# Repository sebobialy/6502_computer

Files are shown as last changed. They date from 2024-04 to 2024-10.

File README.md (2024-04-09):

# 6502_computer
Simple 6502 DIY computer for peripheral prototyping
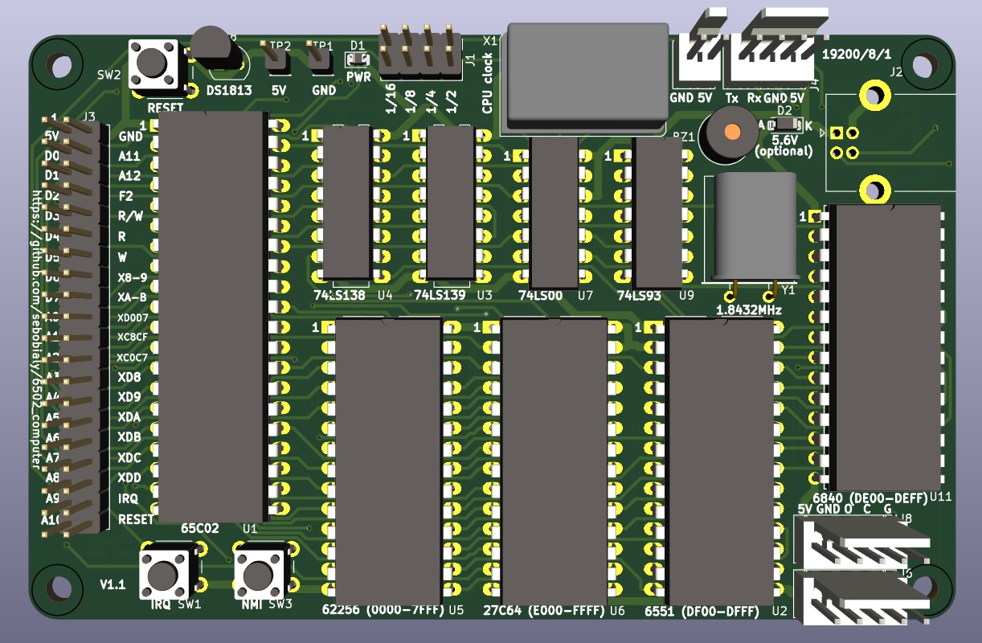
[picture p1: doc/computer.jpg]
6502_computer

**This is a work in progress. Do not try to manufacture yet.**
# Features
1. 65C02 with selectable speed
2. 6551 UART/ACIA with optional USB support via CH340N
3. 6840 clock chip (with buzzer attached)
4. CPU bus accessible, with several selection signals for various parts of memory
5. SyMon III directly working through UART/USB
6. Simple emulator
7. PCB with all possible markings, memory map, and values
8. Compact form, retro look&feel

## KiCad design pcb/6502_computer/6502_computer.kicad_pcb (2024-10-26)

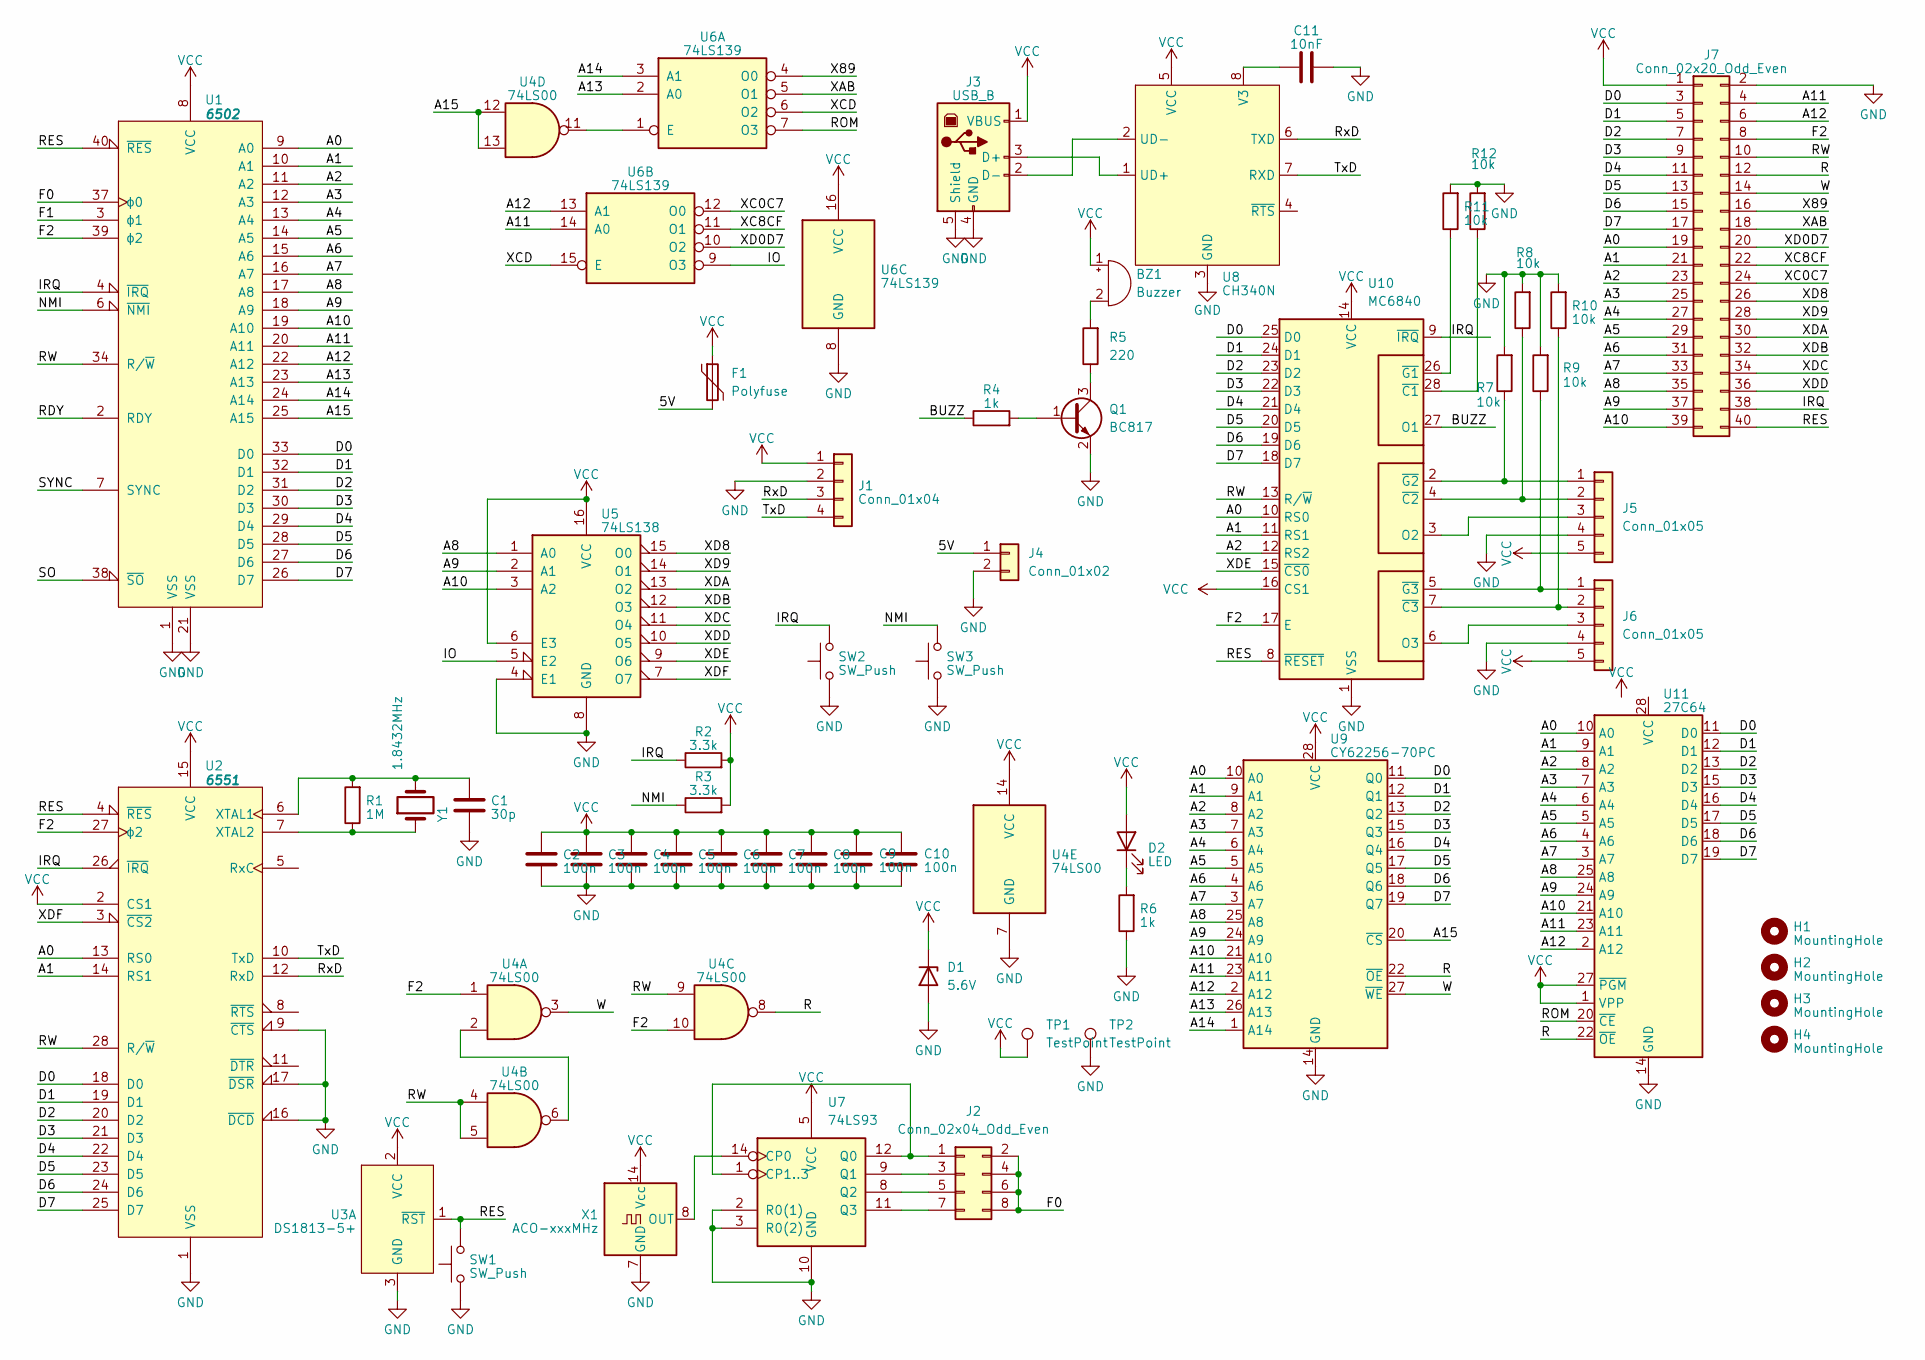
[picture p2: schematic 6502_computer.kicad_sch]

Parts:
BZ1: Buzzer; MagneticBuzzer_Kingstate_KCG0601
C1: 30p; C_0805_2012Metric
C2, C3, C4, C5, C6, C7, C8, C9, C10: 100n; C_0805_2012Metric
C11: 10nF; C_0805_2012Metric
D1: 5.6V; D_SOD-123
D2: LED; D_0805_2012Metric
F1: Polyfuse; Fuse_0805_2012Metric
H1, H2, H3, H4: MountingHole; MountingHole_3.2mm_M3
J1: Conn_01x04; Molex_KK-254_AE-6410-04A_1x04_P2.54mm_Vertical
J2: Conn_02x04_Odd_Even; PinHeader_2x04_P2.54mm_Vertical
J3: USB_B; USB_B_Lumberg_2411_02_Horizontal
J4: Conn_01x02; Molex_KK-254_AE-6410-02A_1x02_P2.54mm_Vertical
J5, J6: Conn_01x05; Molex_KK-254_AE-6410-05A_1x05_P2.54mm_Vertical
J7: Conn_02x20_Odd_Even; PinHeader_2x20_P2.54mm_Vertical
Q1: BC817; SOT-23
R1: 1M; R_0805_2012Metric
R2, R3: 3.3k; R_0805_2012Metric
R4, R6: 1k; R_0805_2012Metric
R5: 220; R_0805_2012Metric
R7, R8, R9, R10, R11, R12: 10k; R_0805_2012Metric
SW1, SW2, SW3: SW_Push; SW_PUSH_6mm_H4.3mm
TP1, TP2: TestPoint; PinHeader_1x01_P2.54mm_Vertical
U1: 6502; DIP-40_W15.24mm_LongPads
U2: 6551; DIP-28_W15.24mm_LongPads
U3: DS1813-5+; TO-92
U4: 74LS00; DIP-14_W7.62mm_LongPads
U5: 74LS138; DIP-16_W7.62mm_LongPads
U6: 74LS139; DIP-16_W7.62mm_LongPads
U7: 74LS93; DIP-14_W7.62mm_LongPads
U8: CH340N; SOP-8_3.9x4.9mm_P1.27mm
U9: CY62256-70PC; DIP-28_W15.24mm_LongPads
U10: MC6840; DIP-28_W15.24mm_LongPads
U11: 27C64; DIP-28_W15.24mm_LongPads
X1: ACO-xxxMHz; Oscillator_DIP-14
Y1: 1.8432MHz; Crystal_HC18-U_Horizontal

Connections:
/5V: F1.2, J4.1
/A0: J7.19, U1.9 (A0), U2.13 (RS0), U9.10 (A0), U10.10 (RS0), U11.10 (A0)
/A1: J7.21, U1.10 (A1), U2.14 (RS1), U9.9 (A1), U10.11 (RS1), U11.9 (A1)
/A2: J7.23, U1.11 (A2), U9.8 (A2), U10.12 (RS2), U11.8 (A2)
/A3: J7.25, U1.12 (A3), U9.7 (A3), U11.7 (A3)
/A4: J7.27, U1.13 (A4), U9.6 (A4), U11.6 (A4)
/A5: J7.29, U1.14 (A5), U9.5 (A5), U11.5 (A5)
/A6: J7.31, U1.15 (A6), U9.4 (A6), U11.4 (A6)
/A7: J7.33, U1.16 (A7), U9.3 (A7), U11.3 (A7)
/A8: J7.35, U1.17 (A8), U5.1 (A0), U9.25 (A8), U11.25 (A8)
/A9: J7.37, U1.18 (A9), U5.2 (A1), U9.24 (A9), U11.24 (A9)
/A10: J7.39, U1.19 (A10), U5.3 (A2), U9.21 (A10), U11.21 (A10)
/A11: J7.4, U1.20 (A11), U6.14 (A0), U9.23 (A11), U11.23 (A11)
/A12: J7.6, U1.22 (A12), U6.13 (A1), U9.2 (A12), U11.2 (A12)
/A13: U1.23 (A13), U6.2 (A0), U9.26 (A13)
/A14: U1.24 (A14), U6.3 (A1), U9.1 (A14)
/A15: U1.25 (A15), U4.12, U4.13, U9.20 (~CS)
/BUZZ: R4.1, U10.27 (O1)
/D0: J7.3, U1.33 (D0), U2.18 (D0), U9.11 (Q0), U10.25 (D0), U11.11 (D0)
/D1: J7.5, U1.32 (D1), U2.19 (D1), U9.12 (Q1), U10.24 (D1), U11.12 (D1)
/D2: J7.7, U1.31 (D2), U2.20 (D2), U9.13 (Q2), U10.23 (D2), U11.13 (D2)
/D3: J7.9, U1.30 (D3), U2.21 (D3), U9.15 (Q3), U10.22 (D3), U11.15 (D3)
/D4: J7.11, U1.29 (D4), U2.22 (D4), U9.16 (Q4), U10.21 (D4), U11.16 (D4)
/D5: J7.13, U1.28 (D5), U2.23 (D5), U9.17 (Q5), U10.20 (D5), U11.17 (D5)
/D6: J7.15, U1.27 (D6), U2.24 (D6), U9.18 (Q6), U10.19 (D6), U11.18 (D6)
/D7: J7.17, U1.26 (D7), U2.25 (D7), U9.19 (Q7), U10.18 (D7), U11.19 (D7)
/F0: J2.2, J2.4, J2.6, J2.8, U1.37 (ϕ0)
/F1: U1.3 (ϕ1)
/F2: J7.8, U1.39 (ϕ2), U2.27 (ϕ2), U4.1, U4.10, U10.17 (E)
/IO: U5.5 (E2), U6.9 (O3)
/NMI: R3.1, SW3.2, U1.6 (~NMI)
/R: J7.12, U4.8, U9.22 (~OE), U11.22 (~OE)
/RDY: U1.2 (RDY)
/RES: J7.40, SW1.2, U1.40 (~RES), U2.4 (~RES), U3.1 (~RST), U10.8 (~RESET)
/ROM: U6.7 (O3), U11.20 (~CE)
/RW: J7.10, U1.34 (R/~W), U2.28 (R/~W), U4.4, U4.5, U4.9, U10.13 (R/~W)
/RxD: J1.3, U2.12 (RxD), U8.6 (TXD)
/SO: U1.38 (~SO)
/SYNC: U1.7 (SYNC)
/TxD: J1.4, U2.10 (TxD), U8.7 (RXD)
/W: J7.14, U4.3, U9.27 (~WE)
/X89: J7.16, U6.4 (O0)
/XAB: J7.18, U6.5 (O1)
/XC0C7: J7.24, U6.12 (O0)
/XC8CF: J7.22, U6.11 (O1)
/XCD: U6.6 (O2), U6.15 (E)
/XD0D7: J7.20, U6.10 (O2)
/XD8: J7.26, U5.15 (O0)
/XD9: J7.28, U5.14 (O1)
/XDA: J7.30, U5.13 (O2)
/XDB: J7.32, U5.12 (O3)
/XDC: J7.34, U5.11 (O4)
/XDD: J7.36, U5.10 (O5)
/XDE: U5.9 (O6), U10.15 (~CS0)
/XDF: U2.3 (~CS2), U5.7 (O7)
GND: C1.1, C2.1, C3.1, C4.1, C5.1, C6.1, C7.1, C8.1, C9.1, C10.1, C11.1, D1.2 (A), J1.2, J3.4 (GND), J3.5 (Shield), J4.2, J5.4, J6.4, J7.2, Q1.2 (E), R6.1, R7.2, R8.2, R9.2, R10.2, R11.2, R12.2, SW1.1, SW2.1, SW3.1, TP2.1, U1.1 (VSS), U1.21 (VSS), U2.1 (VSS), U2.9 (~CTS), U2.16 (~DCD), U2.17 (~DSR), U3.3 (GND), U4.7 (GND), U5.4 (E1), U5.8 (GND), U6.8 (GND), U7.2 (R0(1)), U7.3 (R0(2)), U7.10 (GND), U8.3 (GND), U9.14 (GND), U10.1 (VSS), U11.14 (GND), X1.7 (GND)
unnamed: BZ1.2 (-), R5.2
unnamed: D2.1 (K), R6.2
unnamed: J2.1, U7.1 (CP1..3), U7.12 (Q0)
unnamed: J2.3, U7.9 (Q1)
unnamed: J2.5, U7.8 (Q2)
unnamed: J2.7, U7.11 (Q3)
unnamed: J3.3 (D+), U8.1 (UD+)
unnamed: J3.2 (D-), U8.2 (UD-)
unnamed: J5.1, R7.1, U10.2 (~G2)
unnamed: J5.2, R8.1, U10.4 (~C2)
unnamed: J5.3, U10.3 (O2)
unnamed: J6.1, R9.1, U10.5 (~G3)
unnamed: J6.2, R10.1, U10.7 (~C3)
unnamed: J6.3, U10.6 (O3)
unnamed: Q1.1 (B), R4.2
unnamed: Q1.3 (C), R5.1
unnamed: C1.2, R1.2, U2.6 (XTAL1), Y1.2
unnamed: R1.1, U2.7 (XTAL2), Y1.1
unnamed: U4.2, U4.6
unnamed: U4.11, U6.1 (E)
unnamed: U7.14 (CP0), X1.8 (OUT)
unnamed: C11.2, U8.8 (V3)
unnamed: R12.1, U10.28 (~C1)
VCC: BZ1.1 (+), C2.2, C3.2, C4.2, C5.2, C6.2, C7.2, C8.2, C9.2, C10.2, D1.1 (K), D2.2 (A), F1.1, J1.1, J3.1 (VBUS), J5.5, J6.5, J7.1, R2.2, R3.2, TP1.1, U1.8 (VCC), U2.2 (CS1), U2.15 (VCC), U3.2 (VCC), U4.14 (VCC), U5.6 (E3), U5.16 (VCC), U6.16 (VCC), U7.5 (VCC), U8.5 (VCC), U9.28 (VCC), U10.14 (VCC), U10.16 (CS1), U11.1 (VPP), U11.27 (~PGM), X1.14 (Vcc)

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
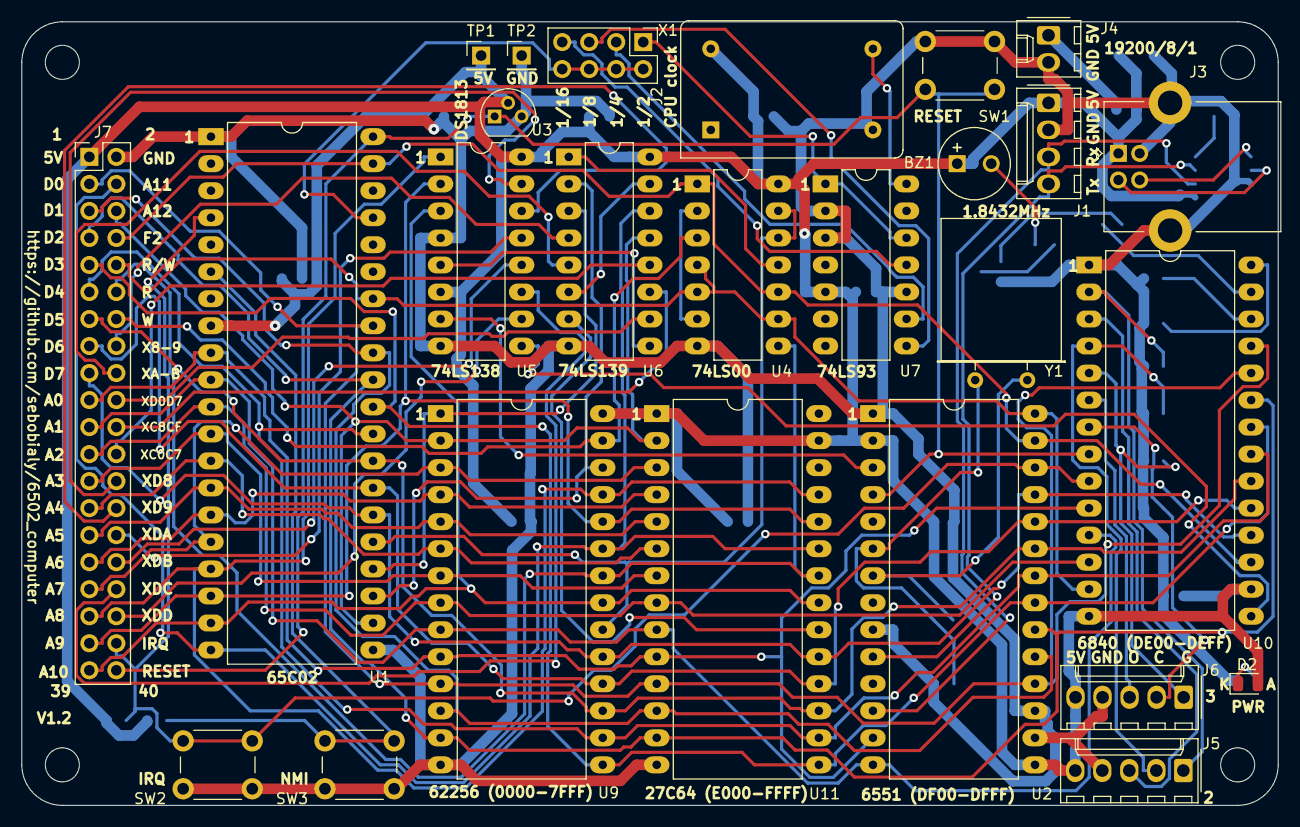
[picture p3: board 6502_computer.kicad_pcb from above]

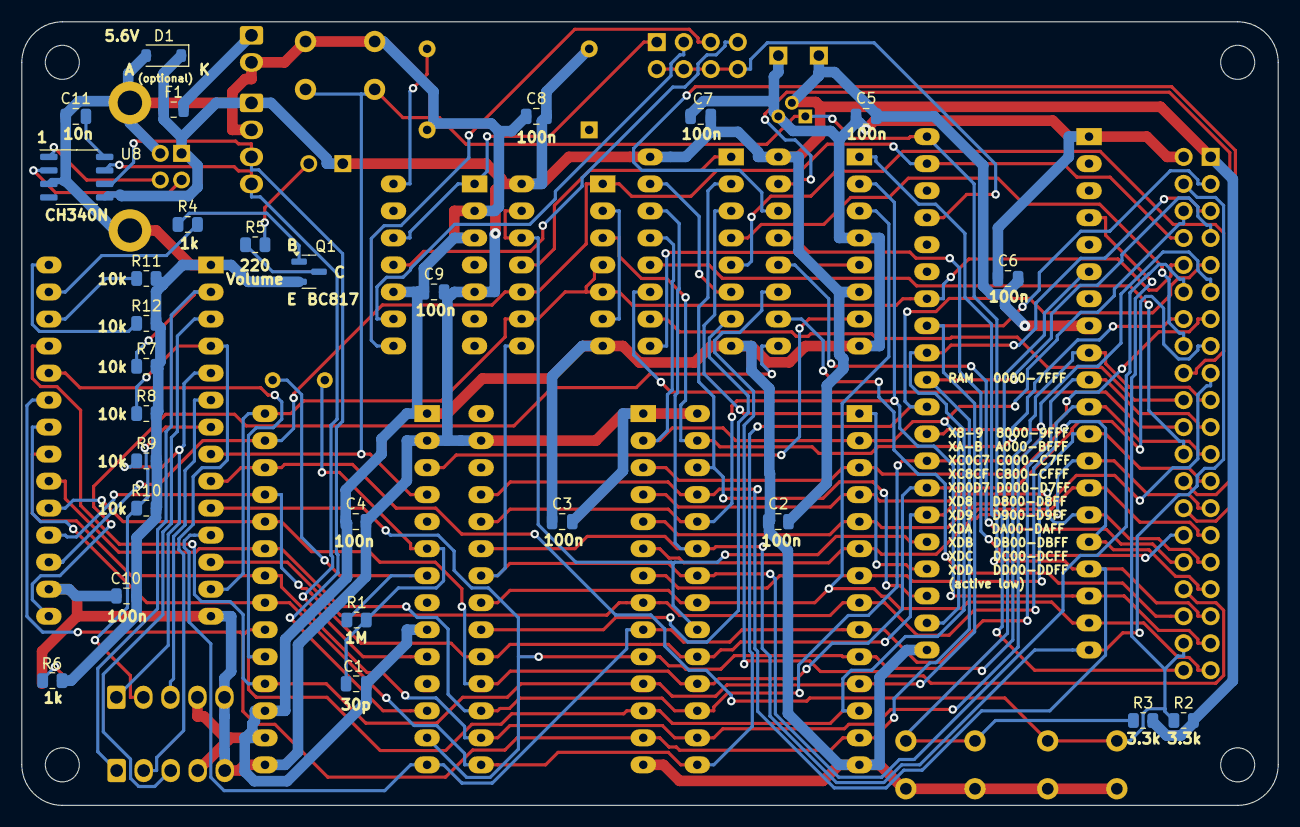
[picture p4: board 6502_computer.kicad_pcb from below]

Board: 2 copper layers, 118.1 x 73.7 mm, 57 parts (27 on the bottom side), 78 nets.

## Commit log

2024-04-07 silkscreen fixes
    [6502_computer.kicad_pcb]
2024-04-09 added timer outputs from 6840
    [6502_computer.kicad_pcb, 6502_computer.kicad_sch]
2024-10-07 fixed problem with not negating E for 74LS139. Buzzer is now using a transistor. 6502 is ZIF friendly.
    [6502_computer.kicad_pcb, 6502_computer.kicad_sch]
2024-10-08 routed 1.2 version
    [6502_computer.kicad_pcb]
2024-10-11 routed v1.2
    [6502_computer.kicad_pcb]
2024-10-26 v1.2 label fixes, pullup resistors for uart, routed
    [6502_computer.kicad_pcb, 6502_computer.kicad_sch]
